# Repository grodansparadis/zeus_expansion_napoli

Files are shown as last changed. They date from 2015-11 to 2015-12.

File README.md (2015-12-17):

<h1>Zeus Expansion Napoli</h1>



CAN add on card with Zeus expansion connector. Fits the 
<a href="http://www.grodansparadis.com/odessa/odessa.html">Odessa</a> module
among other modules.

<hr>

This project is part of the <a href="http://www.vscp.org">VSCP (Very Simple Control Protocol) project</a>. 

<hr>

This project is licensed under the 
<a href="http://creativecommons.org/licenses/by-nc-sa/3.0/">Creative Commons open source license Attribution-NonCommercial-ShareAlike 3.0 Unported</a>. 
Other license options are available by conacting <a href="malto:info@grodansparadis.com">Paradis of the Frog AB</a>

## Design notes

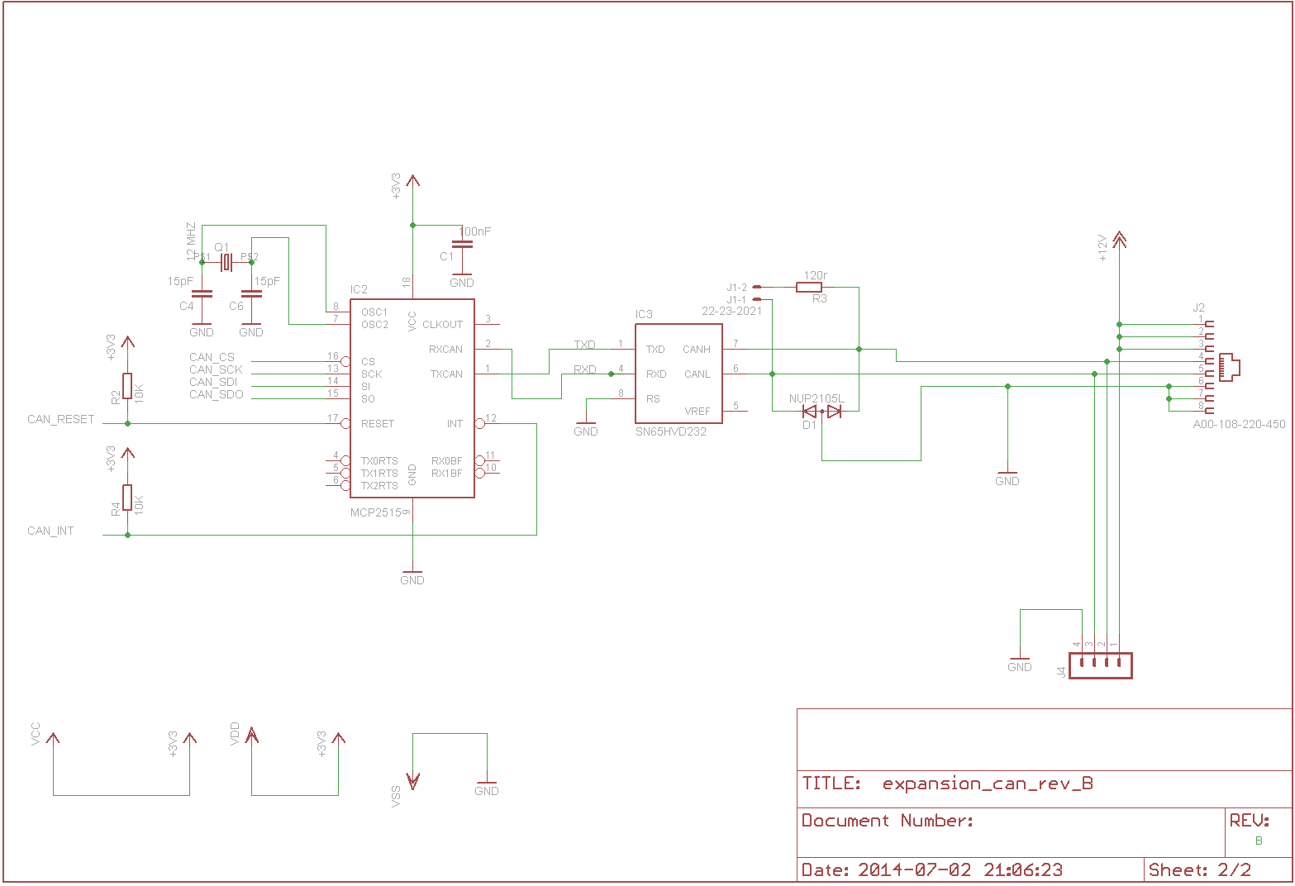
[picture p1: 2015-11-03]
eagle/napoli_sch2_rev_B.png

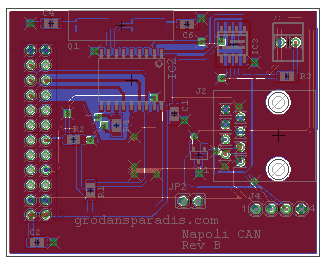
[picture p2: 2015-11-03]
eagle/napoli_brd_rev_B.png

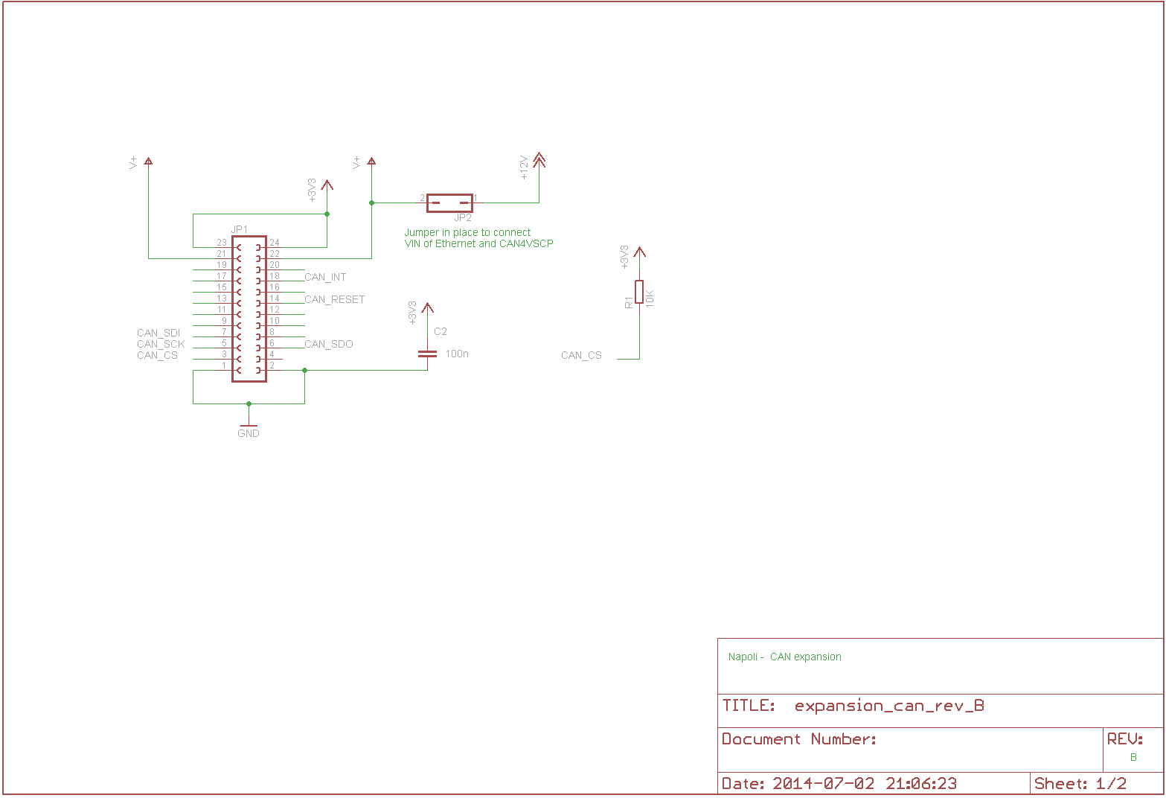
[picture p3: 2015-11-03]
eagle/napoli_sch1_rev_B.png

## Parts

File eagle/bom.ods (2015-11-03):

Partl | ist exported fro | m C:/Users/akhe/Do | cuments/dev | elopment/hardware_zeus/Ethernet/etherne | t module/snow_expansion/c | an/expans | ion_can_rev_a.sch a | t 2011-10-03 22:11 | :18
Part | Value | Device | Package | Description | Description | Supplier | Partnumber | Price
C1 | 100nF | C-EUC0805 | C0805 | CAPACITOR, European symbol | Avkopplingskondensator | Bejoken | 522526 | 0,07
C2 | 100n | C-EUC0805 | C0805 | CAPACITOR, European symbol | 100nF Cheramic capacitor | Bejoken | 522526 | 0,07
C4 | 15pF | C-EUC0805 | C0805 | CAPACITOR, European symbol | Kondensator | Bejoken | 522419 | 0,11
C6 | 15pF | C-EUC0805 | C0805 | CAPACITOR, European symbol | Kondensator | Bejoken | 522419 | 0,11
D1 | NUP2105L | DIODE-2CA|ACSOT23 | SOT23 | Dual DIODE Cathode-Anode|Anode-Cathode | Tansient protection | Digikey | NUP2105LT1GOSCT-ND | 4
IC2 | MCP2515 | MCP2515 | SO-18W |  | CAN Controller | Digikey | MCP2515-I/SO-ND | 15,84
IC3 | SN65HVD232 | MCP2551SN | SO-08 | High Speed CAN tranceiver | 3.3V CAN tranceiver | Digikey | 296-15381-1-ND | 26,05
J1 | 22-23-2021 | 22-23-2021 | 22-23-2021 | .100" (2.54mm) Center Header - 2 Pin | Enkel stiftlist | Digikey | SAM1035-50-ND | 0,33
J2 | A00-108-220-450 | A00-108-220-450 | RJ-45 |  | RJ-45 connector | Digikey | 151-1099-nd | 5,6
JP1 |  | FE12-2 | FE12-2 | FEMALE HEADER |  | Digikey | SAM1212-50-ND | 6,18
Q1 | 12 MHZ | HC-49S | 9C | Digikey 887-1050-1-nd | Crystal | Digikey | 887-1053-1-ND | 2,56
R1 | 10K | R-EU_R0805 | R0805 | RESISTOR, European symbol | Resistor | Bejoken | 454676 | 0,01
R2 | 10K | R-EU_R0805 | R0805 | RESISTOR, European symbol | Resistor | Bejoken | 454676 | 0,01
R3 | 120r | R-EU_R0805 | R0805 | RESISTOR, European symbol | Resistor | Bejoken | 454626 | 0.011
R4 | 10K | R-EU_R0805 | R0805 | RESISTOR, European symbol | Resistor | Bejoken | 454676 | 0,01
 |  |  |  |  |  |  |  | 60,95

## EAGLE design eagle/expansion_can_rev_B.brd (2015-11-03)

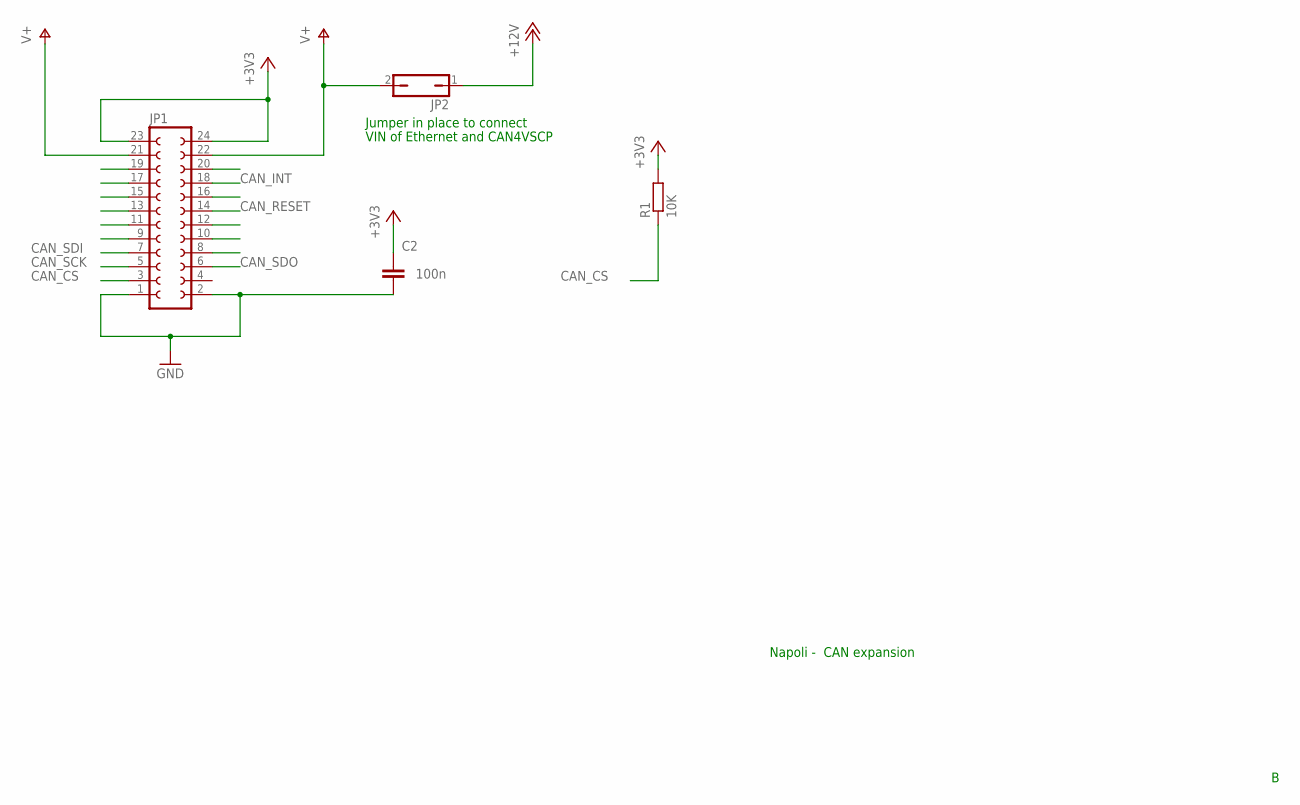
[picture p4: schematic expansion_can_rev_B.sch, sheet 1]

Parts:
C2: 100n; C0805
JP1: FE12-2
JP2: JP1Q; JP1
R1: 10K; R0805

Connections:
+3V3: C2.1, JP1.23, JP1.24, R1.2; also elsewhere on the board
+12V: JP2.1; also elsewhere on the board
CAN_CS: JP1.3, R1.1; also elsewhere on the board
CAN_INT: JP1.18; also elsewhere on the board
CAN_RESET: JP1.14; also elsewhere on the board
CAN_SCK: JP1.5; also elsewhere on the board
CAN_SDI: JP1.7; also elsewhere on the board
CAN_SDO: JP1.6; also elsewhere on the board
GND: C2.2, JP1.1, JP1.2; also elsewhere on the board
VIN: JP1.21, JP1.22, JP2.2

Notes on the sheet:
Napoli - CAN expansion
Jumper in place to connect
VIN of Ethernet and CAN4VSCP

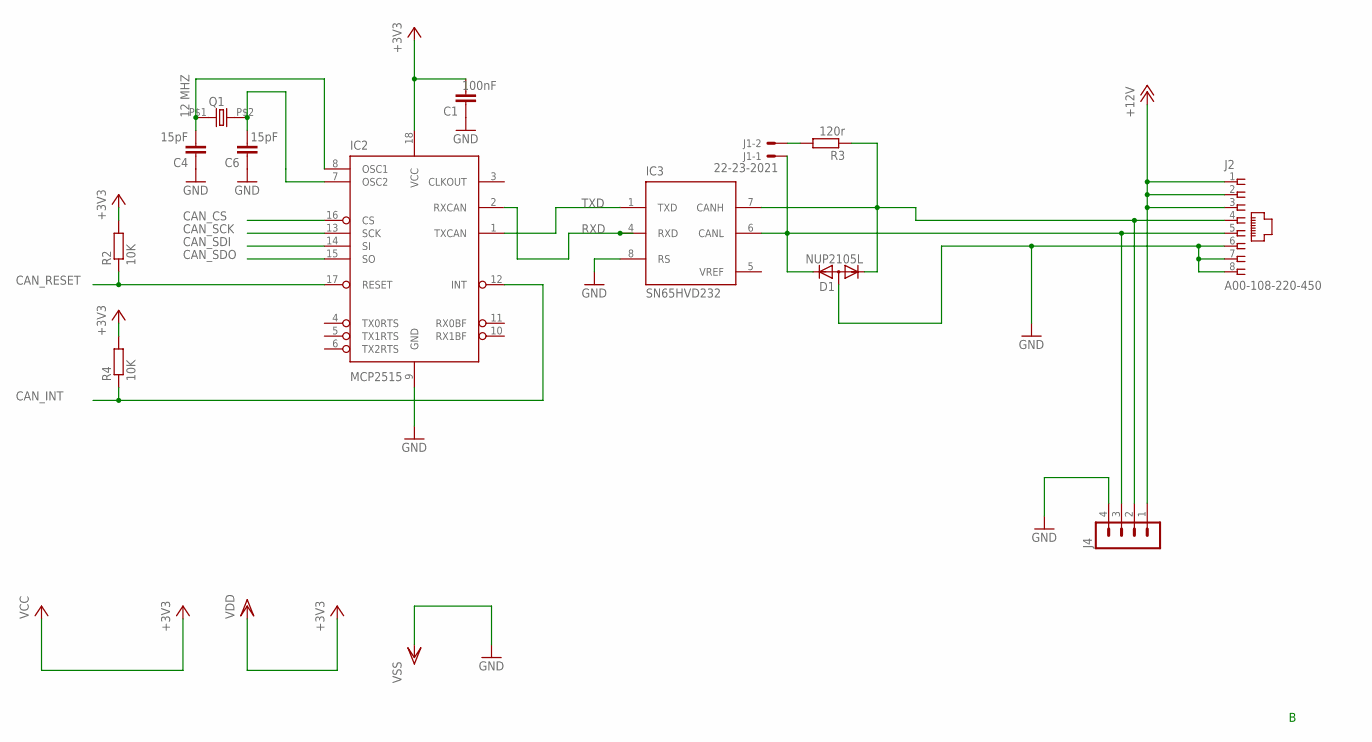
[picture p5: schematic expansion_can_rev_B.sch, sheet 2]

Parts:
C1: 100nF; C0805
C4, C6: 15pF; C0805
D1: NUP2105L; SOT23
IC2: MCP2515; SO-18W
IC3: SN65HVD232; SO-08
J1: 22-23-2021
J2: A00-108-220-450; RJ-45
J4: MA04-1
Q1: 12 MHZ; 9C
R2, R4: 10K; R0805
R3: 120r; R0805

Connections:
+3V3: C1.2, IC2.18 (VCC), IC3.3 (VDD), R2.2, R4.2; also elsewhere on the board
+12V: J2.1, J2.2, J2.3, J4.1; also elsewhere on the board
CANH: D1.1 (K1), IC3.7 (CANH), J2.4, J4.2, R3.1
CANL1: D1.2 (K2), IC3.6 (CANL), J1.1, J2.5, J4.3
CAN_CS: IC2.16 (CS); also elsewhere on the board
CAN_INT: IC2.12 (INT), R4.1; also elsewhere on the board
CAN_RESET: IC2.17 (RESET), R2.1; also elsewhere on the board
CAN_SCK: IC2.13 (SCK); also elsewhere on the board
CAN_SDI: IC2.14 (SI); also elsewhere on the board
CAN_SDO: IC2.15 (SO); also elsewhere on the board
GND: C1.1, C4.1, C6.1, D1.3 (A), IC2.9 (GND), IC3.2 (VSS), IC3.8 (RS), J2.6, J2.7, J2.8, J4.4; also elsewhere on the board
unnamed: J1.2, R3.2
unnamed: C4.2, IC2.8 (OSC1), Q1.P$1 (1)
unnamed: C6.2, IC2.7 (OSC2), Q1.P$2 (2)
RXD: IC2.2 (RXCAN), IC3.4 (RXD)
TXD: IC2.1 (TXCAN), IC3.1 (TXD)
VREF: IC3.5 (VREF)

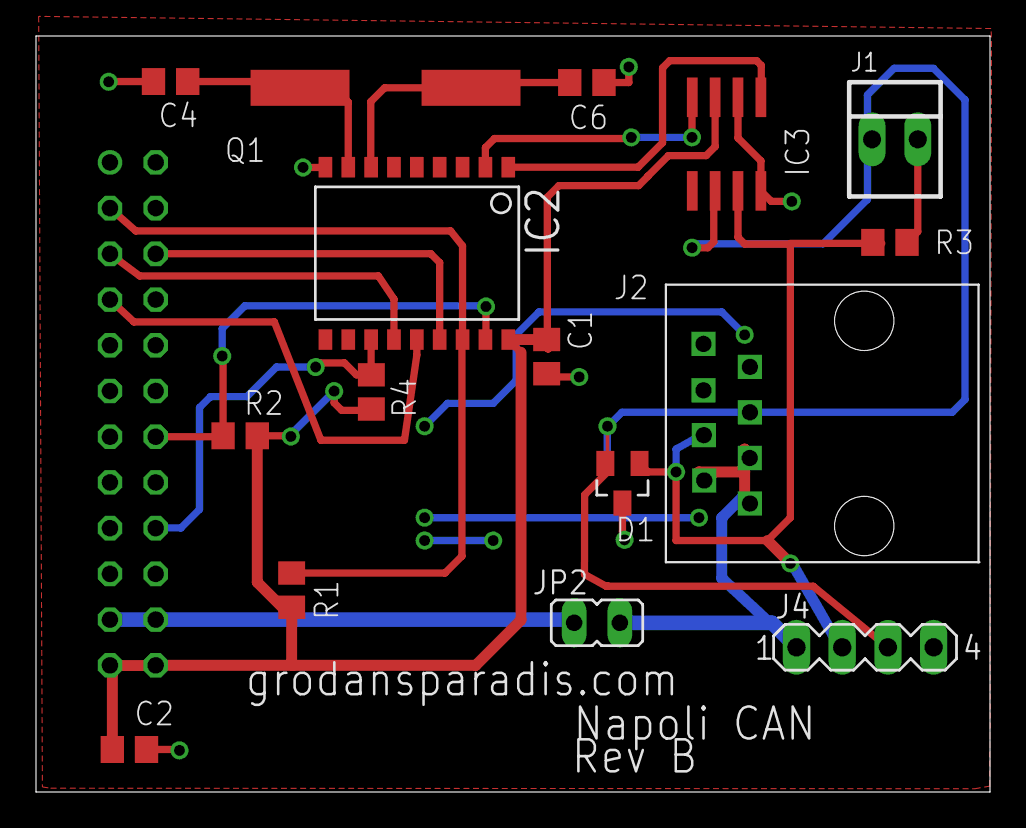
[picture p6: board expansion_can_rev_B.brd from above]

Board: 2 copper layers, 53.0 x 42.0 mm, 17 parts (1 on the bottom side), 17 nets.

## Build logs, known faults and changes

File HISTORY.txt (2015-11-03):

Snow CAN expansion
==================

2011-12-20 - AKHE Added pinlist for power and CAN.
2011-11-10 - AKHE +/- changed position + is at 1,2,3
2011-11-10 - AKHE CANH should be on pin 4 of RJ-45
2011-11-10 - Rev B

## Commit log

2015-11-03 Making design open
    [bom.ods, expansion_can_rev_B.brd, expansion_can_rev_B.sch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]
2015-11-03 Cleaned up some junk
    [bom.ods, expansion_can_rev_B.brd, expansion_can_rev_B.sch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]
